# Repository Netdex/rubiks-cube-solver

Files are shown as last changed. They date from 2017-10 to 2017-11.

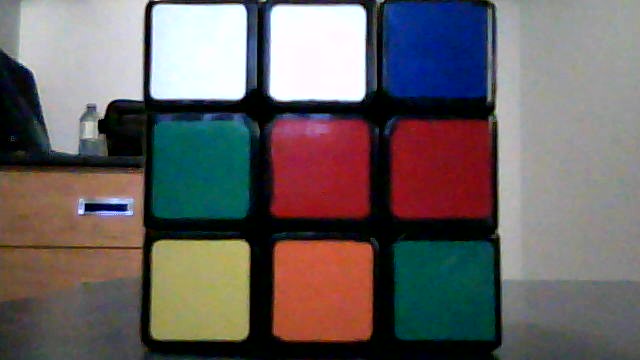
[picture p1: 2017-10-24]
code/experimental/rubik_face.jpg

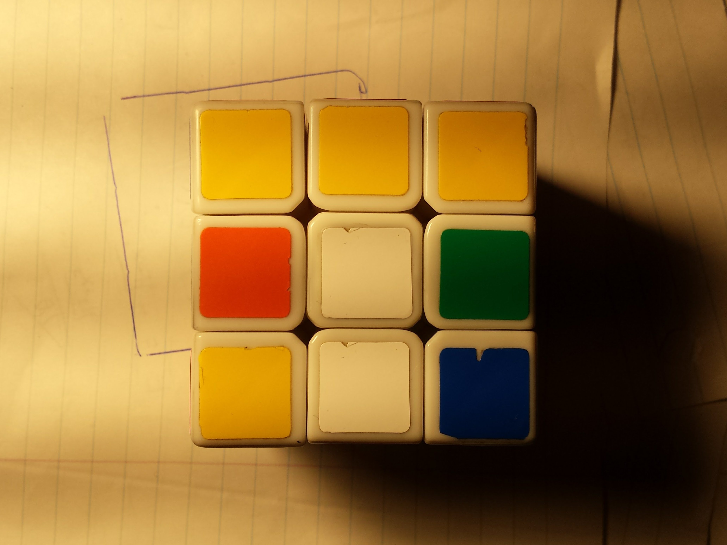
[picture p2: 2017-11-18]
code/experimental/05.jpg

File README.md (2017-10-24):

Add/remove notes as you see fit

## Project Structure
```
bin/        - compiled binaries
obj/        - storage for object files to reduce recompilation
src/        - .c        implementation
include/    - .h        headers
lib/        - .so .a    external lib
```
note: headers files outside of `include/` will not be included compile-time<br>
note: source files outside of `src/` will not be compiled

## Building
```
cd code
make
```
`make run` to execute immediately.<br>
`make clean` to remove binaries.

**Make sure the program is executed from the `bin/` directory**, since many cache files are generated.

## Code Style
- avoid polluting global namespace with short global variables
- attach meaningful prefixes to global functions/variables
- avoid defining short or generic macros
- fix all compile warnings immediately
- split implementation into simple parts
- validate input, use `LOG()` in `util/log.h` for error messages rather than printf

## 3rd Party
ckociemba - 3x3x3 rubik's cube solution search

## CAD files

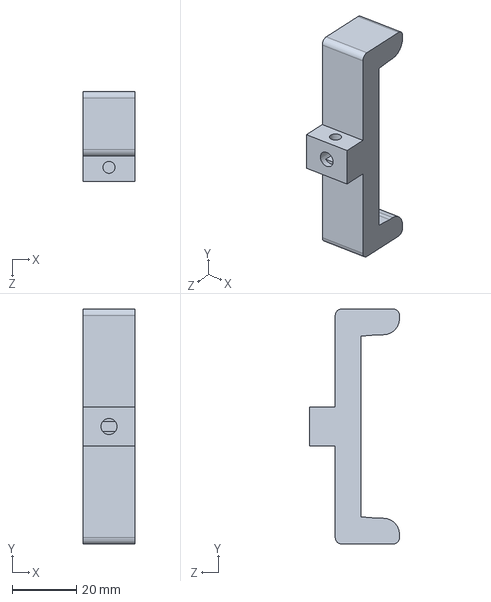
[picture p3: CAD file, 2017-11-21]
solidworks/cube_gripper.sldprt
16.0 x 73.0 x 28.0 mm

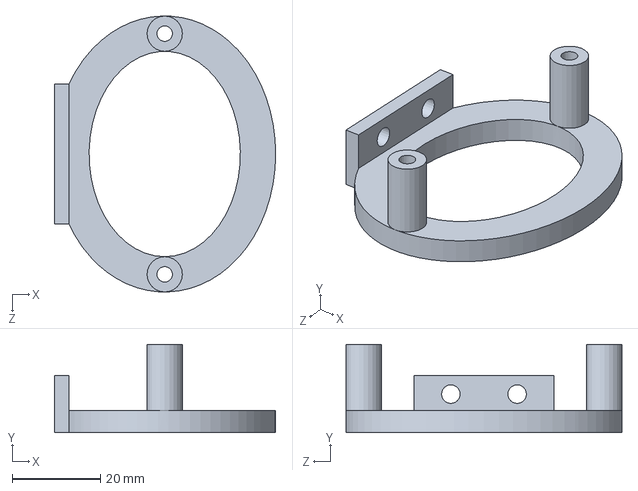
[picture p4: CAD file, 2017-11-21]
solidworks/camera_mount.sldprt
50.1 x 20.0 x 62.5 mm

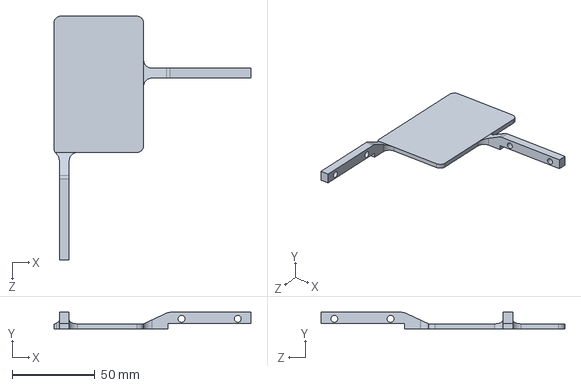
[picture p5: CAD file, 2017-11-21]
solidworks/lcd_holder.sldprt
119.2 x 10.00 x 147.5 mm

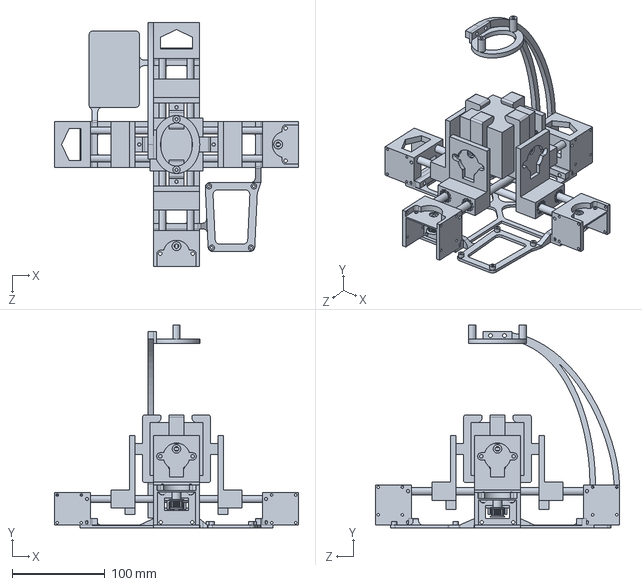
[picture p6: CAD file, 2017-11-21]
solidworks/solver.SLDPRT
263.1 x 218.7 x 263.1 mm

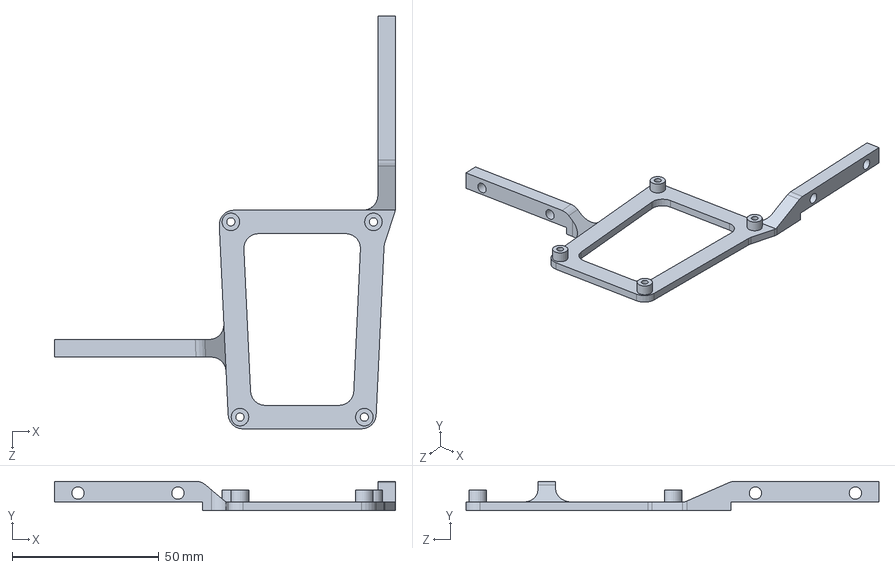
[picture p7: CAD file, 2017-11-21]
solidworks/bbb_holder.sldprt
116.0 x 10.00 x 140.4 mm

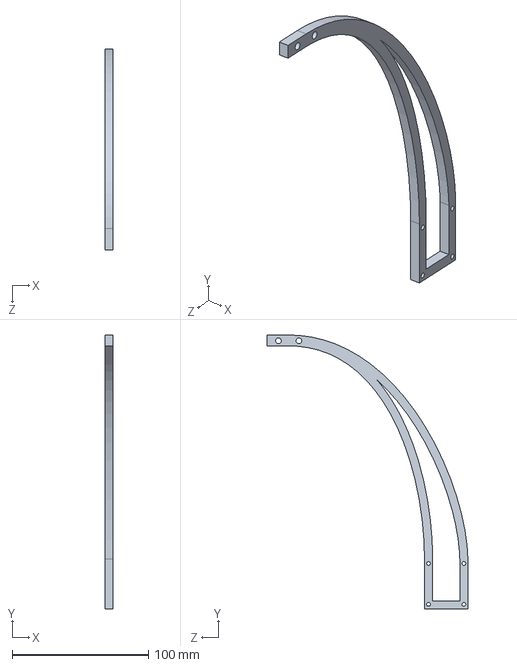
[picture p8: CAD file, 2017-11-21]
solidworks/camera_arm.sldprt
6.00 x 201.1 x 147.4 mm

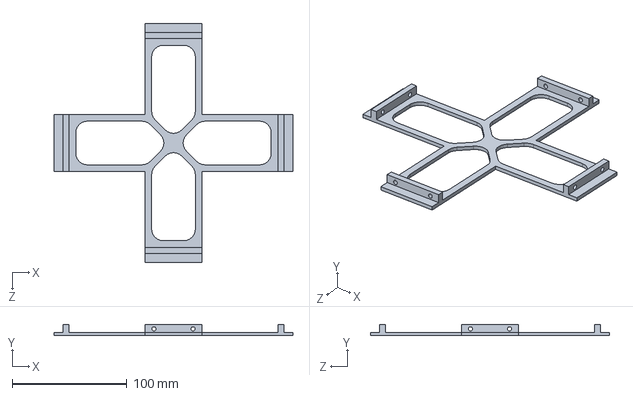
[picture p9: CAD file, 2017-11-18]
solidworks/base.sldprt
208.0 x 10.00 x 208.0 mm

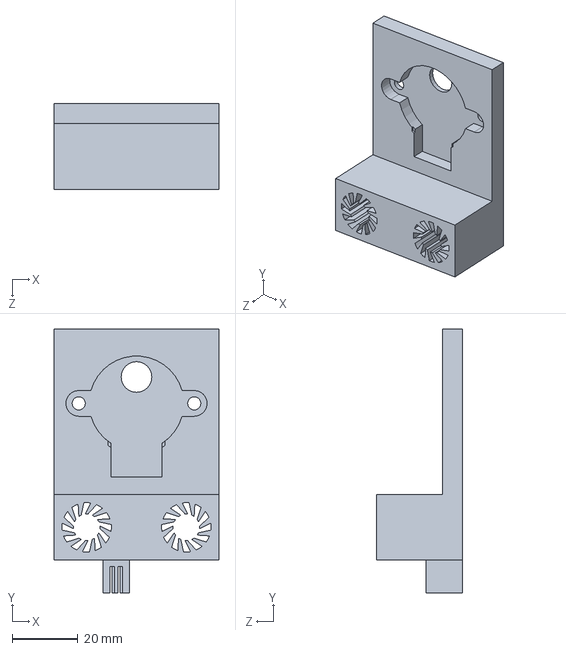
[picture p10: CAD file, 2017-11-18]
solidworks/motion_carriage.sldprt
50.0 x 80.0 x 26.0 mm

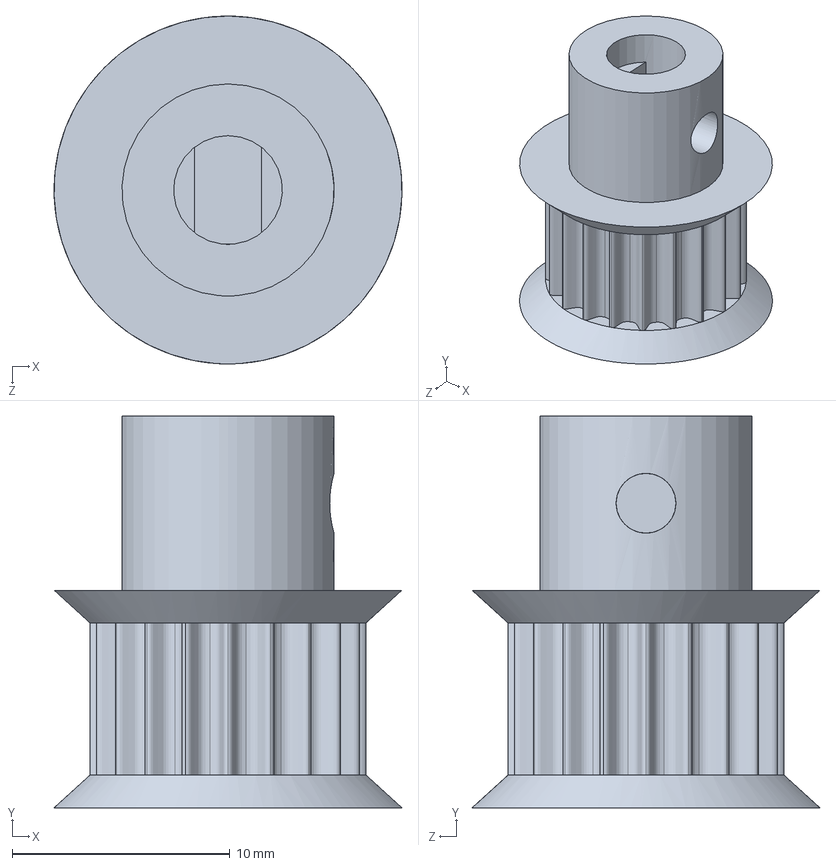
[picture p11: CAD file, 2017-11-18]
solidworks/belt_pulley.SLDPRT
16.0 x 18.0 x 16.0 mm

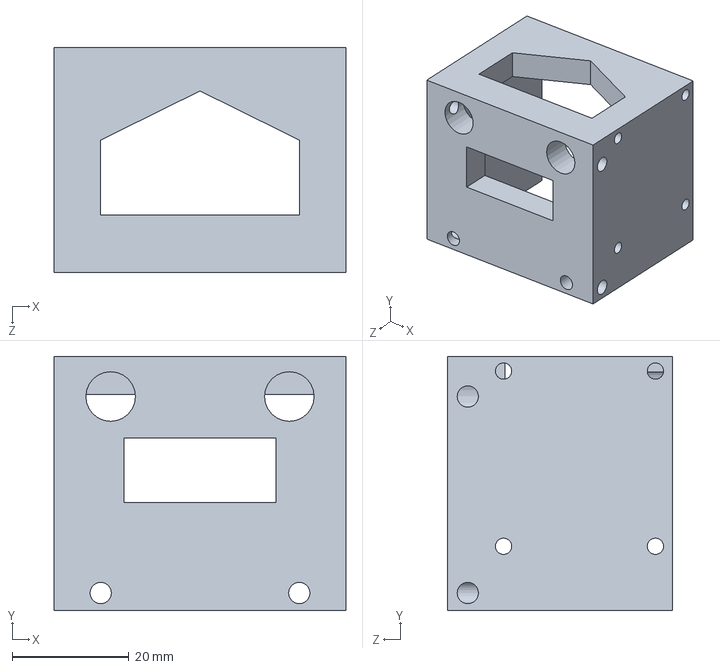
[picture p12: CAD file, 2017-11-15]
solidworks/belt_bearing_holder.sldprt
50.0 x 43.5 x 38.6 mm

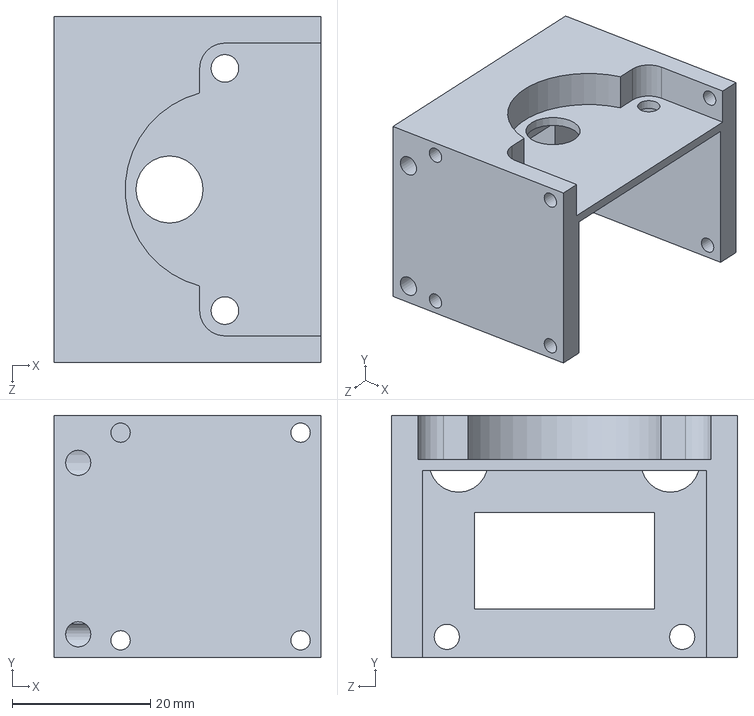
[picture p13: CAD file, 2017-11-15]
solidworks/belt_motor_holder_short.sldprt
38.6 x 35.0 x 50.0 mm

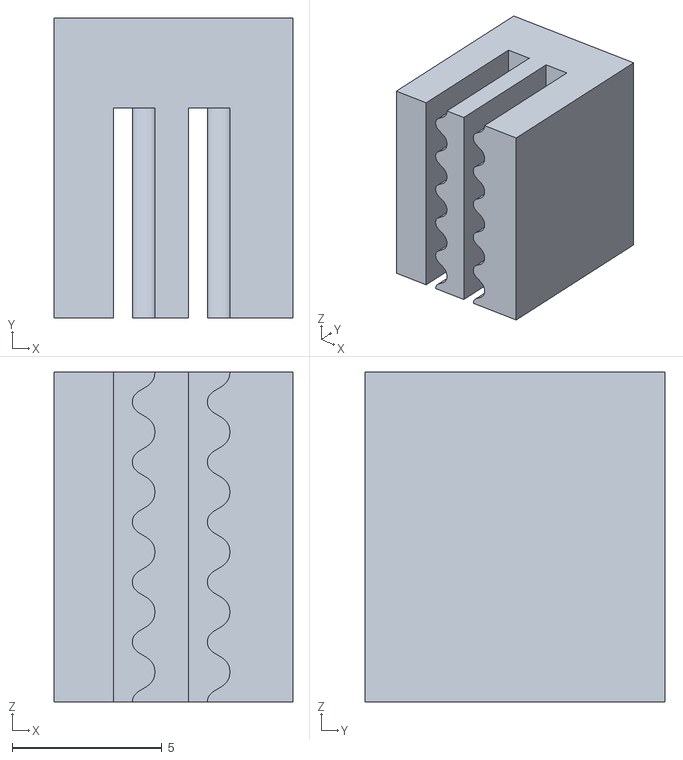
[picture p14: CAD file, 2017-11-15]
solidworks/belt_test.STL
7.96 x 9.99 x 11.0

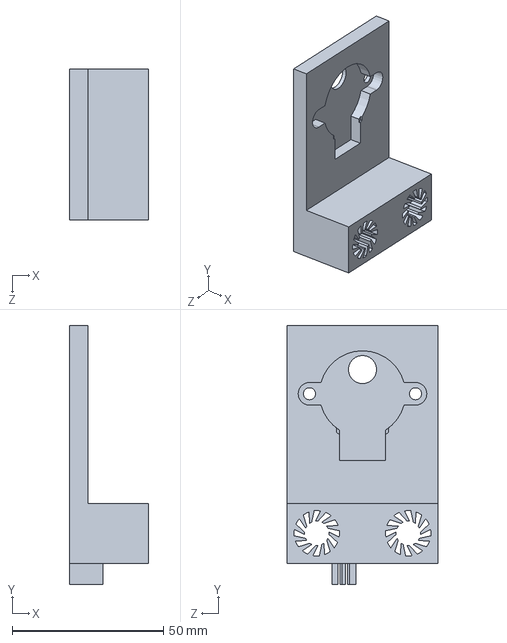
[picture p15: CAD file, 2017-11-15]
solidworks/motion_carriage_tall.sldprt
26.0 x 85.5 x 50.0 mm

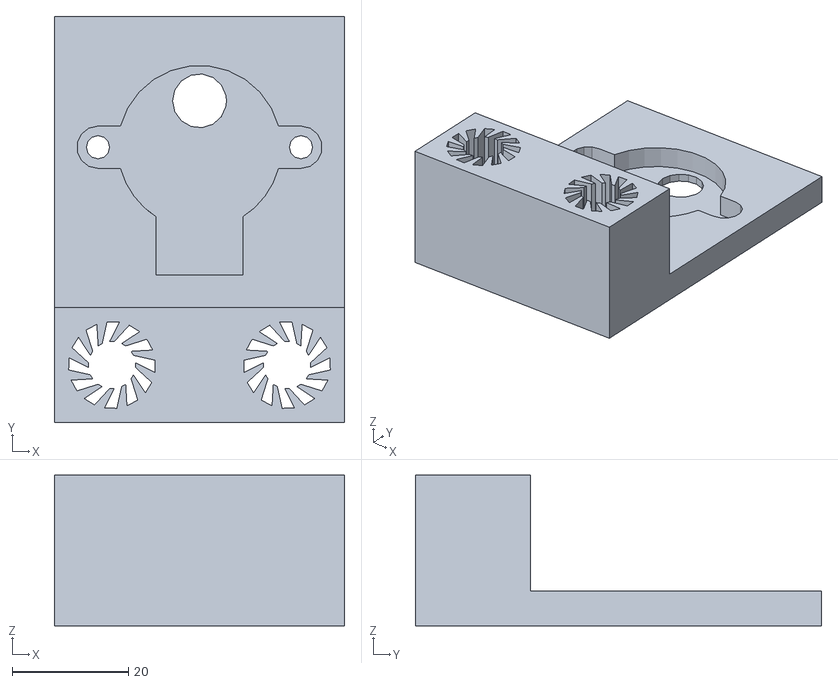
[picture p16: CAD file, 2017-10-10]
solidworks/stepper_carriage.STL
50.0 x 70.0 x 26.0

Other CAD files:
solidworks/belt_motor_holder.sldprt
solidworks/belt_bearing_holder_short.sldprt
solidworks/base.STL
solidworks/bbb_holder.STL
solidworks/belt_bearing_holder.STL
solidworks/belt_bearing_holder_short.STL
solidworks/belt_motor_holder.STL
solidworks/belt_motor_holder_short.STL
solidworks/belt_pulley.STL
solidworks/camera_arm.STL
solidworks/camera_mount.STL
solidworks/cube_gripper.STL
solidworks/lcd_holder.STL
solidworks/motion_carriage.STL
solidworks/motion_carriage_tall.STL

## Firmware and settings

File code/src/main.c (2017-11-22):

#include <stdafx.h>

#include "cube/rubik.h"
#include "cube/solver.h"
#include "cv/color.h"
#include "cv/cube_classify.h"
#include "motor_op.h"
#include "motor.h"

#include "stb_image.h"

extern motor motors[6];

/*int main(void) {

    motor_op_init();

    //steps(-40, motors[MOTOR_FB]);

    char* checkerboards = "D2 F R2 U F' U' L D' U' F U F2 U F2 L B L' D' L' R U2 B' R' D' F ";

    rubik_sequence_t succ = rubik_make_sequence(checkerboards);
    rubik_sequence_t succc = rubik_cube_remove_up_down(&succ);
    rubik_sequence_display(&succc);

    for(int i = 0; i < succc.length; i++){
        if(succc.operations[i].rotation != R_NOSIDE){
            log_debug("execute rotate %c",
                RUBIK_MAP_ROT_CHAR[succc.operations[i].rotation]);
            motor_op_rotate_cube(succc.operations[i].rotation);
        }

        if(succc.operations[i].side != R_NOSIDE
            && succc.operations[i].direction != R_NODIR){
            log_debug("execute face %c%c",
                RUBIK_MAP_FACE_CHAR[succc.operations[i].side],
                RUBIK_MAP_DIR_CHAR[succc.operations[i].direction]);

            motor_op_rotate_face(
                FACE_TO_MOTOR[succc.operations[i].side],
                succc.operations[i].direction);
        }
    }

    motor_op_arms_move(ARM_FB, ARM_EXTEND, ARM_LR, ARM_EXTEND);
    */

    //steps(-40, motors[MOTOR_LR]);

    //motor_op_rot(MOTOR_R, DIR_CW);
    /*
    motor_op_rots(MOTOR_R, DIR_CW, MOTOR_L, DIR_CCW);
    motor_op_rots(MOTOR_F, DIR_CW, MOTOR_B, DIR_CCW);
    */
   /*
    motor_op_rotate_cube(R_FRONT);
    motor_op_rotate_cube(R_RIGHT);
    motor_op_rotate_face(MOTOR_R, DIR_CW);
    */

    //motor_op_arms_move(ARM_FB, ARM_EXTEND, ARM_LR, ARM_EXTEND);
    //motor_op_arms_move(ARM_FB, ARM_RETRACT, ARM_LR, ARM_RETRACT);

    /*
    h_turn_d(motors[0], motors[1], DIR_CW, DIR_CCW);
    h_turn_d(motors[2], motors[3], DIR_CW, DIR_CW);
    steps(-2900, motors[4]);
    q_turn_d(motors[0], motors[1], DIR_CW, DIR_CCW);
    steps(2900, motors[4]);
    steps(-2900, motors[5]);
    q_turn_d(motors[0], motors[1], DIR_CW, DIR_CCW);
    steps(2900, motors[5]);
    h_turn_d(motors[2], motors[3], DIR_CW, DIR_CW);


    motor_op_reset();

    return 0;
}*/

/* full cube rotations to perform while scanning */
rubik_side_t    SCAN_CUBE_OP_MAT[]           = {R_LEFT, R_LEFT, R_LEFT, R_FRONT, R_UP, R_NOSIDE};
/* face rotations to orient final cube */
rubik_dir_t     SCAN_IMAGE_OP_MAT[]          = {R_NODIR, R_CW, R_NODIR, R_NODIR, R_CCW, R_DOUBLE_CW};
/* map scan order to rubiks cube face order (ie. FBLRUD -> URFDLB) */
int             SCAN_ORDER_TO_FACE_ORDER[]   = {2, 5, 4, 1, 0, 3};
/* (x1, y1) (x2, y2) coordinates region containing cube face */
//const int       SCAN_BOUNDS[]                = {1064, 546, 3061, 2549};

/* reads images from file for debugging */
int fake_idx = 0;
uint8_t* fake_cube_classify_read_webcam(int *width, int *height, int *bpp){
    char buf[256];
    sprintf(buf, "../experimental/0%d.jpg", fake_idx++);
    return stbi_load(buf, width, height, bpp, 3);
}

rubik_cube_t scan_cube(){
    uint8_t *image;
    rgb_t color_mat[6][3][3];
    int width, height, bpp, i = 0;
    // image every face, and create rgb matrices of each face based on average color

    // Image front face
    motor_op_rotate_cube(R_BACK);
    image = cube_classify_read_webcam(&width, &height, &bpp);
    log_info("read face %d", i);
    cube_classify_face_image_argb(image, bpp, width, height,
        color_mat[SCAN_ORDER_TO_FACE_ORDER[i]]);
    free(image);
    i++;

    // Image back face
    motor_op_rotate_cube(R_FRONT);
    motor_op_rotate_cube(R_FRONT);
    image = cube_classify_read_webcam(&width, &height, &bpp);
    log_info("read face %d", i);
    cube_classify_face_image_argb(image, bpp, width, height,
        color_mat[SCAN_ORDER_TO_FACE_ORDER[i]]);
    free(image);
    i++;

    // Image left face
    motor_op_rotate_cube(R_BACK);
    motor_op_rotate_cube(R_RIGHT);
    image = cube_classify_read_webcam(&width, &height, &bpp);
    log_info("read face %d", i);
    cube_classify_face_image_argb(image, bpp, width, height,
        color_mat[SCAN_ORDER_TO_FACE_ORDER[i]]);
    free(image);
    i++;

    // Image right face
    motor_op_rotate_cube(R_LEFT);
    motor_op_rotate_cube(R_LEFT);
    image = cube_classify_read_webcam(&width, &height, &bpp);
    log_info("read face %d", i);
    cube_classify_face_image_argb(image, bpp, width, height,
        color_mat[SCAN_ORDER_TO_FACE_ORDER[i]]);
    free(image);
    i++;

    // Image top face
    motor_op_rotate_cube(R_RIGHT);
    motor_op_rots(MOTOR_L, DIR_CW, MOTOR_R, DIR_CCW);
    motor_op_arm_move(ARM_LR, ARM_RETRACT);
    motor_op_arm_move(ARM_FB, ARM_EXTEND);
    image = cube_classify_read_webcam(&width, &height, &bpp);
    log_info("read face %d", i);
    cube_classify_face_image_argb(image, bpp, width, height,
        color_mat[SCAN_ORDER_TO_FACE_ORDER[i]]);
    free(image);
    i++;

    // Image bottom face
    motor_op_rotate_cube(R_FRONT);
    motor_op_rotate_cube(R_FRONT);
    image = cube_classify_read_webcam(&width, &height, &bpp);
    log_info("read face %d", i);
    cube_classify_face_image_argb(image, bpp, width, height,
        color_mat[SCAN_ORDER_TO_FACE_ORDER[i]]);
    free(image);
    motor_op_rotate_cube(R_BACK);

    /*for(int i = 0; i < 6; i++){
        // remove "fake" for real case
        image = cube_classify_read_webcam(&width, &height, &bpp);
        log_info("read face %d", i);
        cube_classify_face_image_argb(image, bpp, width, height,
            color_mat[SCAN_ORDER_TO_FACE_ORDER[i]]);
        free(image);
        if (SCAN_CUBE_OP_MAT[i] != R_NOSIDE) {
            motor_op_rotate_cube(SCAN_CUBE_OP_MAT[i]);
        }
    }*/
    log_trace("cube color output:");

    for(int f = 0; f < 6; f++){
        for(int y = 0; y < 3; y++){
            char dbuf[1024] = {0};
            for(int x = 0; x < 3; x++){
                char tbuf[256] = {0};
                sprintf(tbuf, "(%.2f,%.2f,%.2f) ", color_mat[f][y][x].r, color_mat[f][y][x].g, color_mat[f][y][x].b);
                strcat(dbuf, tbuf);
            }
            log_trace("%s", dbuf);
        }
        log_trace("");
    }
    log_info("classifying...");
    rubik_cube_t cube = cube_classify_from_colors(color_mat);
    log_info("cube built!");

    // since the faces are not necessarily imaged in the correct orientation,
    // rotate them accordingly
    for(int i = 0; i < 6; i++){
        cube.faces[i] = rubik_face_rotate(cube.faces[i], SCAN_IMAGE_OP_MAT[i]);
    }
    return cube;
}

int main(void){

    rubik_sequence_t seqLOL = rubik_make_sequence("R2 L2 F2 B2 U2 D2 ");
    //rubik_sequence_rotate(&seqLOL, 0, seqLOL.length, R_FRONT);

    log_info("rotated sequence: %s", rubik_sequence_to_string(&seqLOL));


    log_info("optimizing sequence...");
    // TODO: transform sequence into a full rotation sequence w/o up and down
    // The solution rubik_cube_remove_up_down needs to be fixed!
    log_info("asdasdasd sequence...");

    rubik_sequence_t fixed = rubik_cube_remove_up_down(&seqLOL);

    log_info("rotated sequence: %s", rubik_sequence_to_string(&fixed));
    /*
    char *strL = rubik_sequence_to_string(&truncc);
    log_info("optimized sequence: %s", strL);
    free(strL);
    */
    return 0;


    log_set_level(LOG_TRACE);

    motor_op_init();

    motor_op_arm_move(ARM_LR, ARM_RETRACT);
    motor_op_arm_move(ARM_FB, ARM_RETRACT);

    rubik_cube_t cube = scan_cube();
    log_trace("cube matrix output:");
    for(int f = 0; f < 6; f++){
        for(int y = 0; y < 3; y++){
            char dbuf[1024] = {0};
            for(int x = 0; x < 3; x++){
                char tbuf[256] = {0};
                sprintf(tbuf, "%d ", cube.faces[f].colors[y][x]);
                strcat(dbuf, tbuf);
            }
            log_trace("%s", dbuf);
        }
        log_trace("");
    }

    rubik_solution_t solution = rubik_solve(cube);
    log_info("generated sequence: %s", solution.str);
    assert(solution.error_code == 0);

    rubik_sequence_rotate(&solution.seq, 0, solution.seq.length, R_FRONT);

    log_info("rotated sequence: %s", solution.str);

    log_info("optimizing sequence...");
    // TODO: transform sequence into a full rotation sequence w/o up and down
    // The solution rubik_cube_remove_up_down needs to be fixed!
    rubik_sequence_t trunc = rubik_cube_remove_up_down(&solution.seq);
    char *str = rubik_sequence_to_string(&trunc);
    log_info("optimized sequence: %s", str);
    free(str);

    log_info("running sequence");
    for(int i = 0; i < trunc.length; i++){
        if(trunc.operations[i].rotation != R_NOSIDE){
            log_debug("execute rotate %c",
                RUBIK_MAP_ROT_CHAR[trunc.operations[i].rotation]);
            motor_op_rotate_cube(trunc.operations[i].rotation);
        }

        if(trunc.operations[i].side != R_NOSIDE
            && trunc.operations[i].direction != R_NODIR){
            log_debug("execute face %c%c",
                RUBIK_MAP_FACE_CHAR[trunc.operations[i].side],
                RUBIK_MAP_DIR_CHAR[trunc.operations[i].direction]);

            motor_op_rotate_face(
                FACE_TO_MOTOR[trunc.operations[i].side],
                trunc.operations[i].direction);
        }
    }
    log_info("done!");

    rubik_destroy_solution(&solution);
    rubik_destroy_sequence(&trunc);
    motor_op_reset();
    return 0;
}

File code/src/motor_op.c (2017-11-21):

#include "stdafx.h"
#include "motor_op.h"
#include "motor.h"

/* DOCUMENTATION IS IN motor_op.h */
/* This file would probably benefit from flowcharts */

/* map rubik_face_t to appropriate motor */
int FACE_TO_MOTOR[] = {-1, 3, 0, -1, 2, 1};
/* index i, is motor steps to achieve operation i */
const int ARM_OP_STEPS[] = {0, 1900, 2950};
/* grabbers A[i] must be vertical when doing a rotation on face i */
int MOTOR_REQ_VERT[4][2] = {
    {MOTOR_L, MOTOR_R},     // F
    {MOTOR_R, MOTOR_L},     // B
    {MOTOR_F, MOTOR_B},     // L
    {MOTOR_B, MOTOR_F}      // R
};
/* grabbers A[i] must be vertical when doing a rotation on face i */
int MOTOR_REQ_VERT_INV[4][2] = {
    {MOTOR_F, MOTOR_B},     // F
    {MOTOR_B, MOTOR_F},     // B
    {MOTOR_L, MOTOR_R},     // L
    {MOTOR_R, MOTOR_L}      // R
};
/* parallel arm to rotation on motor i */
int ROT_ARM[4] = { MOTOR_FB, MOTOR_FB, MOTOR_LR, MOTOR_LR};
/* perpendicular arm to rotation on motor i */
int PERP_ARM[4] = { MOTOR_LR, MOTOR_LR, MOTOR_FB, MOTOR_FB };

/* GPIO pinout for motors */
motor motors[] = {
    {9, 11, 12, 13, 14}, // F
    {8, 37, 38, 39, 40}, // B
    {8, 33, 34, 35, 36}, // L
    {8, 11, 12, 13, 14}, // R
    {8, 7, 8, 9, 10},    // F/B retract/extend
    {8, 15, 16, 17, 18}, // L/R retract/extend
};

/* motor position state for optimizing moves */


union motor_op_state {
    struct {
        // (vertical = 0, horizontal = 1)
        int f;      // position of front grabber
        int b;      // position of back grabber
        int l;      // position of left grabber
        int r;      // position of right grabber
        // (retracted = 0, partial = 1, extended = 2)
        int fb;     // position of f/b arm
        int lr;     // position of l/r arm
    };
    int pos[6];    // grabber positions
} state = {{G_VERT, G_VERT, G_VERT, G_VERT, ARM_EXTEND, ARM_EXTEND}};

void motor_op_rot(int motor, int op){
    assert(motor >= MOTOR_F && motor <= MOTOR_R);
    assert(op >= DIR_CW && op <= DIR_DCW);
    
    if(op >= DIR_DCW){
        h_turn(motors[motor], op);
    } else {
        state.pos[motor] = !state.pos[motor];
        q_turn(motors[motor], op);
    }
    motor_op_reset();
    //log_trace("F: %d B: %d L: %d R: %d FB: %d LR: %d", state.pos[0], state.pos[1], state.pos[2], state.pos[3], state.pos[4], state.pos[5]);
}

void motor_op_rots(int motor1, int op1, int motor2, int op2){
    assert(motor1 >= MOTOR_F && motor1 <= MOTOR_R);
    assert(motor2 >= MOTOR_F && motor2 <= MOTOR_R);
    assert(op1 >= DIR_CW && op1 <= DIR_DCW);
    assert(op2 >= DIR_CW && op2 <= DIR_DCW);

    if (op1 < DIR_DCW) state.pos[motor1] = !state.pos[motor1];
    if (op2 < DIR_DCW) state.pos[motor2] = !state.pos[motor2];
    
    // Move both motors together.
    if (op1 >= DIR_DCW && op2 >= DIR_DCW) {
        h_turn_d(motors[motor1], motors[motor2], op1, op2);

    }
    else {
        q_turn_d(motors[motor1], motors[motor2], op1, op2);
        if (op1 >= DIR_DCW) {
            q_turn(motors[motor1], op1);
        }
        if (op2 >= DIR_DCW) {
            q_turn(motors[motor2], op2);
        }
    }
    motor_op_reset();
    //log_trace("F: %d B: %d L: %d R: %d FB: %d LR: %d", state.pos[0], state.pos[1], state.pos[2], state.pos[3], state.pos[4], state.pos[5]);
}

void motor_op_arm_move(int arm, int op){
    assert(arm >= MOTOR_FB && arm <= MOTOR_LR);
    assert(op >= ARM_RETRACT && op <= ARM_EXTEND);

    int delta = ARM_OP_STEPS[state.pos[arm]] - ARM_OP_STEPS[op];
    state.pos[arm] = op;
    if(delta != 0) {
        steps(delta, motors[arm]);
    }
    motor_op_reset();
    //log_trace("F: %d B: %d L: %d R: %d FB: %d LR: %d", state.pos[0], state.pos[1], state.pos[2], state.pos[3], state.pos[4], state.pos[5]);
}

void motor_op_arms_move(int arm1, int op1, int arm2, int op2){
    assert(arm1 >= ARM_FB && arm1 <= ARM_LR);
    assert(arm2 >= ARM_FB && arm2 <= ARM_LR);
    assert(arm1 != arm2);

    int delta1 = ARM_OP_STEPS[state.pos[arm1]] - ARM_OP_STEPS[op1];
    int delta2 = ARM_OP_STEPS[state.pos[arm2]] - ARM_OP_STEPS[op2];

    state.pos[arm1] = op1;
    state.pos[arm2] = op2;

    int sign1 = delta1 < 0 ? -1 : 1;
    int sign2 = delta2 < 0 ? -1 : 1;
    
    // move both motors together
    for(int i = 0; i < max(abs(delta1), abs(delta2)); i++){
        if(i < abs(delta1))
            step(sign1 * i, motors[arm1]);
        if(i < abs(delta2))
            step(sign2 * i, motors[arm2]);
        nsleep(DELAY);
    }
    motor_op_reset();
    //log_trace("F: %d B: %d L: %d R: %d FB: %d LR: %d", state.pos[0], state.pos[1], state.pos[2], state.pos[3], state.pos[4], state.pos[5]);
}

void motor_op_init(){
#ifndef NO_GPIO
    log_debug("initializing motors...");
    iolib_init();
    for (int i = 0; i < 6; i++) {
        motor_init(motors[i]);
    }
#endif
}

void motor_op_reset(){
#ifndef NO_GPIO
    log_debug("resetting motors...");
    for (int i = 0; i < 6; i++) {
        motor_free(motors[i]);
    }
#endif
}

/*
 * Motor Operation: Sequence Execution
 * 
 * Steps to execute a seequence:
 * Consider current operation
 * 1. If exist, perform curr op rot
 * Consider next operation
 * 2. If not exist next op rot, and
 *    curr op face opposes next op face,
 *    perform concurrent motor_op_rots
 * 3. Else, perform motor_op_rot curr
 * 4. Increment op dep. rots/rot
 */
void motor_op_perform_sequence(rubik_sequence_t seq){
    // TODO

}

/*
 * Motor Operation: Face Rotation
 * 
 * Steps to rotate a face:
 * 1. Check if perp grabbers are vertical.
 *    If they are, skip to step 4.
 * 2. Partial extend perp arm.
 * 3. Rotate perp grabbers to vertical.
 * 4. Ensure perp arm is retracted.
 * 5. Ensure parallel arm is retracted.
 * 6. Turn face by direction.
 */
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

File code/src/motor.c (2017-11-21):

#include "stdafx.h"

#include "motor.h"

void motor_init(motor m) {
    iolib_setdir(m.bank, m.pin1, BBBIO_DIR_OUT);
    iolib_setdir(m.bank, m.pin2, BBBIO_DIR_OUT);
    iolib_setdir(m.bank, m.pin3, BBBIO_DIR_OUT);
    iolib_setdir(m.bank, m.pin4, BBBIO_DIR_OUT);
    pin_low(m.bank, m.pin1);
    pin_low(m.bank, m.pin2);
    pin_low(m.bank, m.pin3);
    pin_low(m.bank, m.pin4);
}

void motor_free(motor m) {
    pin_low(m.bank, m.pin1);
    pin_low(m.bank, m.pin2);
    pin_low(m.bank, m.pin3);
    pin_low(m.bank, m.pin4);
}
void step(int step, motor m) {
    step %= 8;
    if (step < 0) step += 16;
    step %= 8;
    switch (step) {
    case 0:
        pin_low(m.bank, m.pin1);
        pin_low(m.bank, m.pin2);
        pin_low(m.bank, m.pin3);
        pin_high(m.bank, m.pin4);
	break;
    case 1:
        pin_low(m.bank, m.pin1);
        pin_low(m.bank, m.pin2);
        pin_high(m.bank, m.pin3);
        pin_high(m.bank, m.pin4);
	break;
    case 2:
        pin_low(m.bank, m.pin1);
        pin_low(m.bank, m.pin2);
        pin_high(m.bank, m.pin3);
        pin_low(m.bank, m.pin4);
	break;
    case 3:
        pin_low(m.bank, m.pin1);
        pin_high(m.bank, m.pin2);
        pin_high(m.bank, m.pin3);
        pin_low(m.bank, m.pin4);
	break;
    case 4:
        pin_low(m.bank, m.pin1);
        pin_high(m.bank, m.pin2);
        pin_low(m.bank, m.pin3);
        pin_low(m.bank, m.pin4);
	break;
    case 5:
        pin_high(m.bank, m.pin1);
        pin_high(m.bank, m.pin2);
        pin_low(m.bank, m.pin3);
        pin_low(m.bank, m.pin4);
	break;
    case 6:
        pin_high(m.bank, m.pin1);
        pin_low(m.bank, m.pin2);
        pin_low(m.bank, m.pin3);
        pin_low(m.bank, m.pin4);
	break;
    case 7:
        pin_high(m.bank, m.pin1);
        pin_low(m.bank, m.pin2);
        pin_low(m.bank, m.pin3);
        pin_high(m.bank, m.pin4);
	break;
    default:
        pin_low(m.bank, m.pin1);
        pin_low(m.bank, m.pin2);
        pin_low(m.bank, m.pin3);
        pin_low(m.bank, m.pin4);
	break;
    }
}

void steps(int steps, motor m) {
    for (int i = 0; i < abs(steps); i++) {
        if (steps < 0) {
            step(-i, m);
        } else {
            step(i, m);
        }
        nsleep(DELAY);
    }
}

void q_turn(motor m, int dir) {
    if (dir == DIR_CW || dir == DIR_DCW) {
        steps(1024 + OVERSHOOT, m);
        steps(-OVERSHOOT, m);
    } else {
        steps(-(1024 + OVERSHOOT), m);
        steps(OVERSHOOT, m);
    }
}

void q_turn_d(motor m1, motor m2, int dir1, int dir2) {
    for (int i = 0; i < 1024 + OVERSHOOT; i++) {
        if (dir1 == DIR_CCW || dir1 == DIR_DCCW) {
            step(-i, m1);
        } else {
            step(i, m1);
        }
        if (dir2 == DIR_CCW || dir2 == DIR_DCCW) {
            step(-i, m2);
        } else {
            step(i, m2);
        }
        nsleep(DELAY);
    }
    for (int i = 0; i < OVERSHOOT; i++) {
        if (dir1 == DIR_CCW || dir1 == DIR_DCCW) {
            step(i, m1);
        } else {
            step(-i, m1);
        }
        if (dir2 == DIR_CCW || dir2 == DIR_DCCW) {
            step(i, m2);
        } else {
            step(-i, m2);
        }
        nsleep(DELAY);
    }
}

void h_turn(motor m, int dir) {
    if (dir == DIR_CW || dir == DIR_DCW) {
        steps(2048 + OVERSHOOT, m);
        steps(-OVERSHOOT, m);
    } else {
        steps(-(2048 + OVERSHOOT), m);
        steps(OVERSHOOT, m);
    }
}

void h_turn_d(motor m1, motor m2, int dir1, int dir2) {
    for (int i = 0; i < 2048 + OVERSHOOT; i++) {
        if (dir1 == DIR_CCW || dir1 == DIR_DCCW) {
            step(-i, m1);
        } else {
            step(i, m1);
        }
        if (dir2 == DIR_CCW || dir2 == DIR_DCCW) {
            step(-i, m2);
        } else {
            step(i, m2);
        }
        nsleep(DELAY);
    }
    for (int i = 0; i < OVERSHOOT; i++) {
        if (dir1 == DIR_CCW || dir1 == DIR_DCCW) {
            step(i, m1);
        } else {
            step(-i, m1);
        }
        if (dir2 == DIR_CCW || dir2 == DIR_DCCW) {
            step(i, m2);
        } else {
            step(-i, m2);
        }
        nsleep(DELAY);
    }
}

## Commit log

2017-10-06 Initial commit with preliminary solidworks design for the cube solver
    [solver.SLDPRT]
2017-10-09 Updated stepper test code with helper methods for quarter and half turns, as well as turning multiple motors
2017-10-09 Designed belt pulley part
    [belt_pulley.SLDPRT, belt_pulley.STL]
2017-10-10 Modified solver files to use built in linear bearings
    [cube_gripper.STL, solver.SLDPRT, stepper_carriage.STL]
2017-10-23 Revert "solver: update makefile"
    This reverts commit c7175c9ba916e43ea190e6dfb1c89d734fffc25e
    [main.c]
2017-10-23 solver: implement solver bindings
    [main.c]
2017-10-23 solver: correct bug with sequence generation
    [main.c]
2017-10-23 solver: fix issue with face direction
    [main.c]
2017-10-24 Added live updating loop showing the current cube face that can be seen
2017-10-25 Finished converting cube colour recognition to use HSV rather than RGB. Also fixed the rgb_to_hsv algorithm in the process
    [main.c]
2017-10-26 rubiks communication: added in first stage algorithm to remove instructions for top and bottom faces, added new enum for rotating the cube, added no change enum for side and direction, modified rubik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
2017-11-01 Started adding belts in solidworks model
    [solver.SLDPRT]
2017-11-02 worked on adding belt motor mounts
    [belt_pulley.SLDPRT, solver.SLDPRT]
2017-11-05 Did a bit of work on the solidworks model
    [solver.SLDPRT]
2017-11-06 Ported motor test code to be more general and use the new GPIO control functions. Also changed usleep to nanosleep
2017-11-08 Fixed LCD code so it works again now. Also fixed a bug with gpio reading giving a segfault.
    [bbb_gpio.c]
2017-11-09 Trying to get motors to work right
2017-11-09 got motors working properly again, using the old BBBIO library instead of my sketch homemade one
2017-11-13 Prepared and exported solidworks files for 3D printing
    [belt_motor_holder.STL, belt_motor_holder.sldprt, belt_test.STL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]
2017-11-14 Prepared more solidworks files for printing. Also designed bearing holders for belts
    [belt_bearing_holder.STL, belt_bearing_holder.sldprt, belt_motor_holder.STL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]
2017-11-15 Fixed up mounting holes on solidworks parts, got more ready for printing
    [belt_bearing_holder_short.STL, belt_bearing_holder_short.sldprt, belt_motor_holder_short.STL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]
2017-11-15 More solidworks tweaks, more exporting for printing
    [belt_bearing_holder.STL, belt_bearing_holder.sldprt, belt_motor_holder.STL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]
2017-11-18 classifier: replaced clustering algorithm with center facelet comparison algorithm
    [main.c]
2017-11-18 Made final tweaks for solid works files, and prepared for printing
    [base.STL, base.sldprt, belt_pulley.SLDPRT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]
2017-11-19 solver: added ability to solve to any target target pattern, not just solved state
    [main.c]
2017-11-19 added cross-compiler building for arm-linux-gnueabihf
2017-11-19 Testing motors
2017-11-20 implemented motor control for face rotations
2017-11-20 partially implemented full rotational motor control
2017-11-20 fixed motor pins
2017-11-20 fix missing delay, begin sequence state
    [main.c, motor_op.c, motor_op.h]
2017-11-20 Updated cube_classify.c to use new regions for camera scanning
2017-11-20 implemented motor control
2017-11-21 Fixed a lot of errors with motor_op causing the robot to crash into itself. Fixed colour registration to use HSV, very accurately now. Main method has also been updated, so the machine is actually ab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
    [main.c, motor.c, motor_op.c]
2017-11-21 Designed camera arm and mount in solidworks
    [bbb_holder.STL, bbb_holder.sldprt, camera_arm.STL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]
